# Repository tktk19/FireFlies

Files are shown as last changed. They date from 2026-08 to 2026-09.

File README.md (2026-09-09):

# FireFlies（電子ホタル集団同期明滅プロジェクト）

自然界のホタル（ゲンジボタル）に見られる**「集団同期明滅（引き込み現象）」**を超小型マイコン（ATtiny402）と光学センサのみで自律的に再現する電子ホタルプロジェクトです。

無線通信や親機（中央制御）を使わず、**「相手の放った光を見る $\to$ わずかに遅れて自分も光る」** という局所的な光フィードバックのみで、複数のホタルモジュールを並べると徐々に呼吸を合わせるように一斉同調発光します。

---

## 🌟 主な特徴・コンセプト

1. **自律分散型の協調発光（引き込みモデル）**
   - 個々のホタルが独立したタイマーで明滅します。
   - 消灯休止中に他のホタルの光を浴びると、休止時間を切り上げて 0.3〜1.2 秒のランダム遅延後に自分も発光を開始します。
   - 複数個が互いの光を浴び合うことで、蔵本モデル（非線形結合振動子の同期現象）のように群れ全体のリズムが自然と揃っていきます。

2. **リアルなゲンジボタルの明滅カーブ**
   - 単純な線形PWMではなく、二乗則を用いた呼吸のような立ち上がり（フェードイン）$\to$ 2〜4秒間の発光維持 $\to$ 余韻を残したフェードアウト $\to$ 4〜10秒間のゆらぎ休止を再現しています。

3. **超低消費電力スリープ（約 1 ヶ月の電池寿命）**
   - ATtiny402 内部の超低消費電力 32.768kHz 発振器と PIT（Periodic Interrupt Timer）を使用。
   - 待機・休止中は CPU を **Power Down スリープ（約 1μA）** させ、125ms（8Hz）ごとに一瞬だけ起きて受光センサをチェック。
   - 小型充電池（LIR2032: 実効約45mAh）でありながら、平均消費電流を約 50μA に抑え、**一晩で電池切れすることなく約 37 日間の連続稼働** を実現しています。

4. **安全なバッテリー過放電保護（UVLO）**
   - マイコン内部の基準電圧を用いて電源電圧（VDD）をリアルタイム監視。
   - 電圧が **3.0V を下回ると LED を短く2回点滅してお知らせし、永久ディープスリープ（消費電流 ~0.1μA）で安全に自動シャットダウン**。
   - 保護回路のないコイン型リチウムイオン電池が危険な過放電（1.2V等のセル破壊域）に陥るのを防ぎます。

5. **5V / 3.7V デュアル電源対応**
   - 設定マクロ（`#define USE_BATTERY_3V7`）を 1 行切り替えるだけで、USB/5V動作確認モードと 3.7V充電池モードに最適化された閾値・輝度が自動適用されます。

---

## 🛠 ハードウェア仕様

| 項目 | 仕様・部品 | 備考 |
| :--- | :--- | :--- |
| **マイコン (MCU)** | Microchip ATtiny402 (SOIC-8) | 超小型8ピンAVR (20MHz/内部発振) |
| **受光センサ** | フォトトランジスタ PT19-21C/L41/TR8 | PA7 / ADC (物理3ピン) + 100kΩ プルアップ |
| **発光素子** | チップLED (緑色 / 0603 or 1608) | PA2 / PWM (物理5ピン) + 4.7kΩ 電流制限抵抗 |
| **電源** | LIR2032 (3.7V 充電式コイン電池, 70mAh)<br>または 5V (USB電源) | CR2032電池ホルダー等に実装 |
| **書き込みインターフェース** | UPDI (MPLAB SNAP 等) | PA0 / UPDI (物理6ピン) + 4.7kΩ プルアップ |
| **筐体** | 3Dプリント外装（リアルなホタル形状） | 作成中 |

---

## 📄 設計資料・回路図リンク (`docs/`)

回路・基板に関する各種設計資料は [`docs/`](docs/) ディレクトリに収録されています。

* **回路図 (SVG)**: [`docs/circuit_v1.svg`](docs/circuit_v1.svg)
  * SchemDraw で描画された視認性の高い回路図
* **回路作図スクリプト**: [`docs/make_circuit_draw.py`](docs/make_circuit_draw.py)
  * Python の SchemDraw ライブラリを用いて回路図 SVG を自動生成するスクリプト
* **回路図 (PDF/EasyEDA)**: [`docs/SCH_Schematic1_2026-09-01.pdf`](docs/SCH_Schematic1_2026-09-01.pdf)
  * EasyEDA で設計された正式な回路図面
* **基板アートワーク (PDF/EasyEDA)**: [`docs/PCB_PCB1_2026-09-01.pdf`](docs/PCB_PCB1_2026-09-01.pdf)
  * 実装基板のレイアウトおよび配線パターン図

### 実機・動作確認ギャラリー (`docs/imgs/`)

| モジュール外観（斜視） | モジュール外観（上面） | 同期明滅テスト風景 |
| :---: | :---: | :---: |
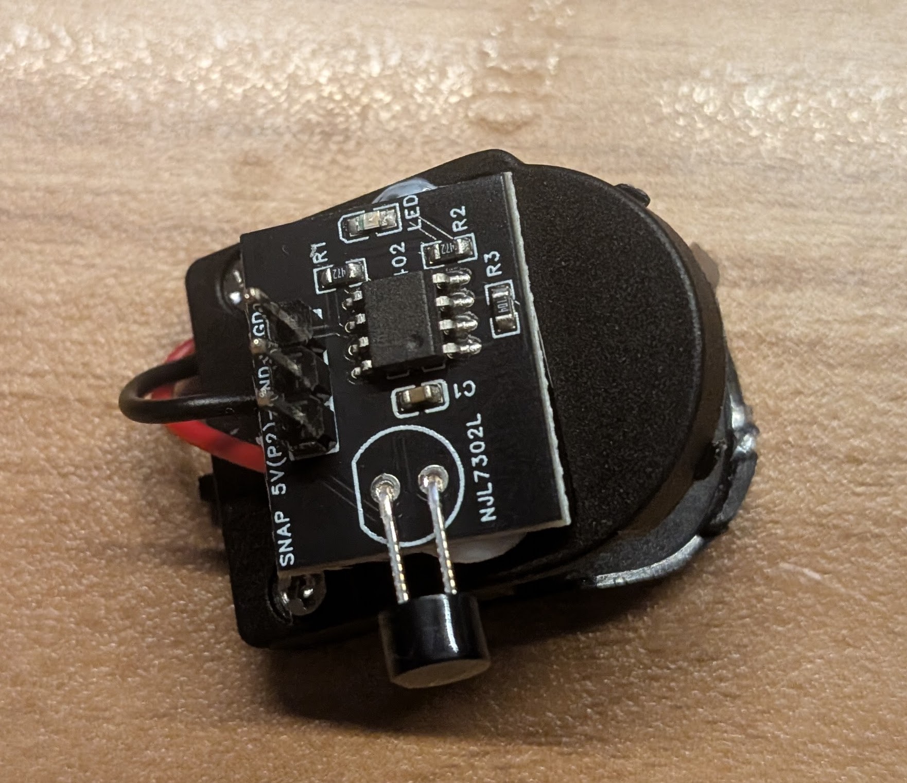
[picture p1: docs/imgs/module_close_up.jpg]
モジュール外観（斜視）
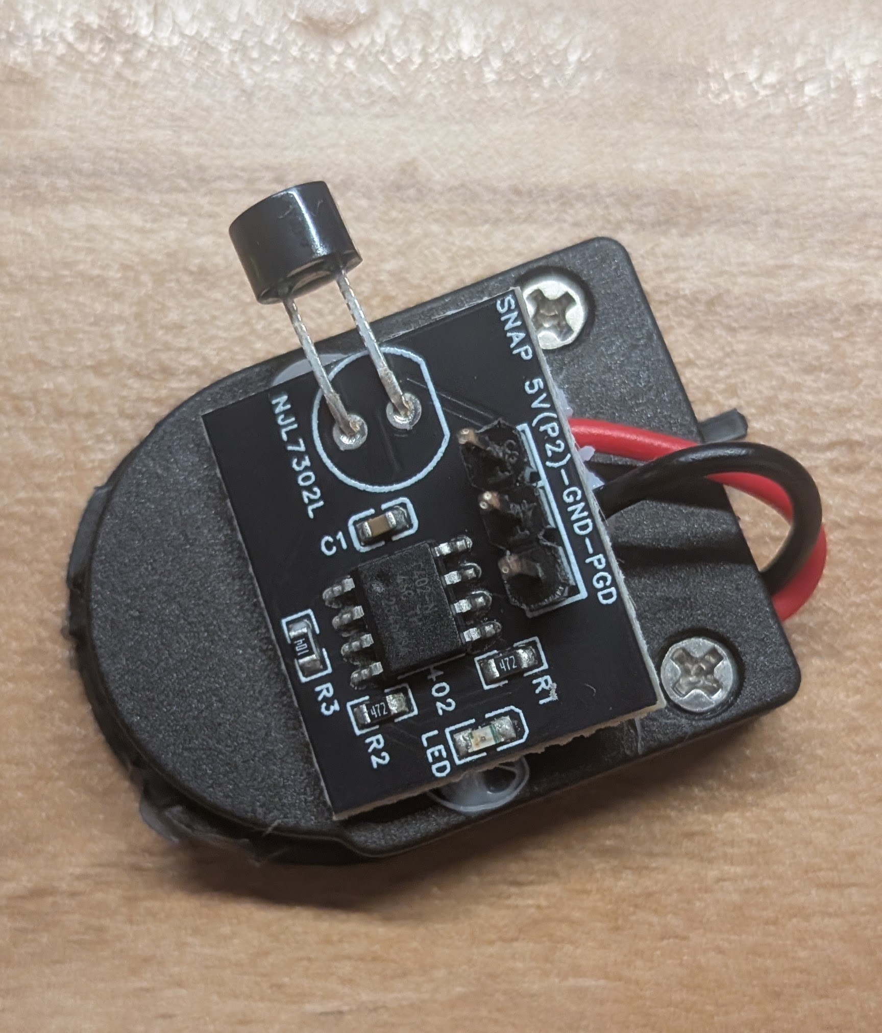
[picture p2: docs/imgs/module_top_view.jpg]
モジュール外観（上面）
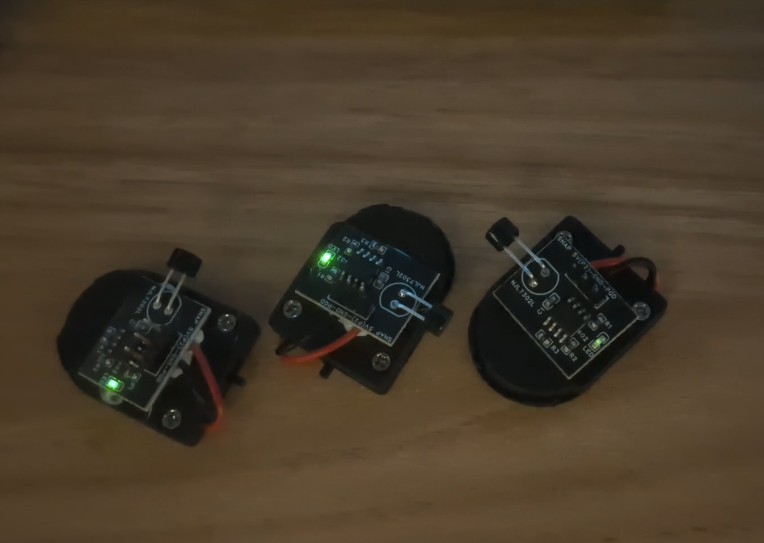
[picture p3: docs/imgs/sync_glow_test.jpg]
同期明滅テスト風景
|  |  |  |

---

## 💻 ソフトウェア・アルゴリズム (`Arduino/FireFly/`)

メインプログラム: [`Arduino/FireFly/FireFly.ino`](Arduino/FireFly/FireFly.ino)

### 状態遷移フロー

```mermaid
stateDiagram-v2
    [*] --> 昼間待機: 電源ON
    昼間待機 --> 夜間モード: 部屋を消灯 (ADC >= DARK_THRESHOLD)
    夜間モード --> 昼間待機: 部屋が明るい (ADC < DARK_THRESHOLD)

    state 夜間モード {
        [*] --> 発光処理: flashFirefly()
        発光処理 --> 自己受光ガード: スリープ2秒 (誤検出防止)
        自己受光ガード --> 休止待機: 4〜10秒 (125ms間隔スリープ)
        
        休止待機 --> 協調発光: 他の光検知 (ADC < LIGHT_THRESHOLD)
        協調発光 --> 発光処理: 0.3〜1.2秒ランダム遅延後
        
        休止待機 --> 自律発光: タイムアウト
        自律発光 --> 発光処理
    }

    夜間モード --> 電池切れシャットダウン: 電圧 < 3.0V (過放電保護)
    電池切れシャットダウン --> [*]: 永久ディープスリープ (0.1μA)
```

### 設定パラメータの比較

| パラメータ名 | 3.7V 充電池モード (`USE_BATTERY_3V7 = true`) | 5V 電源モード (`USE_BATTERY_3V7 = false`) | 説明 |
| :--- | :--- | :--- | :--- |
| `DARK_THRESHOLD` | **800** (約2.9V以上) | **819** (4.0V以上) | 周囲が暗くなった（夜）と判定するADC閾値 |
| `LIGHT_THRESHOLD` | **640** (約2.3V以下) | **720** (約3.5V以下) | 他のホタルの光を検知するADC閾値 |
| `ABSOLUTE_MAX_BRIGHTNESS` | **255** (100% PWM) | **200** (約78% PWM) | LED発光の最大輝度 |
| `LOW_BATTERY_VOLTAGE_MV` | **3000 mV** (3.0V) | **0 mV** (無効) | 過放電保護シャットダウン閾値 |

---

## 📂 ディレクトリ構成

```text
FireFlies/
├── README.md               # 本ドキュメント
├── Arduino/
│   ├── FireFly/
│   │   └── FireFly.ino     # ホタル同期発光ファームウェア（スリープ＆過放電保護内蔵）
│   └── LEDTest/            # LED・受光テスト用スケッチ
├── docs/                   # 回路図・基板設計資料
│   ├── circuit_v1.svg      # 回路図 (SVG)
│   ├── make_circuit_draw.py# 回路作図スクリプト
│   ├── SCH_Schematic1_2026-09-01.pdf # 回路図面 (PDF)
│   └── PCB_PCB1_2026-09-01.pdf       # 基板レイアウト図面 (PDF)
├── 3DModel/                # 外装・モデルデータ (.3mf, .png, Pythonスクリプト)
└── EasyEDA/                # EasyEDA プロジェクトファイル格納用
```

---

## 🔧 ビルド・書き込み方法

1. **開発環境の準備**:
   * Arduino IDE をインストール。
   * ボードマネージャに **`megaTinyCore`**（by Spence Konde）を導入。
2. **ボード設定**:
   * ボード: `ATtiny402/202`
   * チップ: `ATtiny402`
   * クロック: `20MHz Internal`（または `16MHz`）
3. **書き込み**:
   * プログラマに UPDI 対応機器（MPLAB SNAP、jtag2updi、SerialUPDI 等）を選択し、ファームウェアを書き込みます。

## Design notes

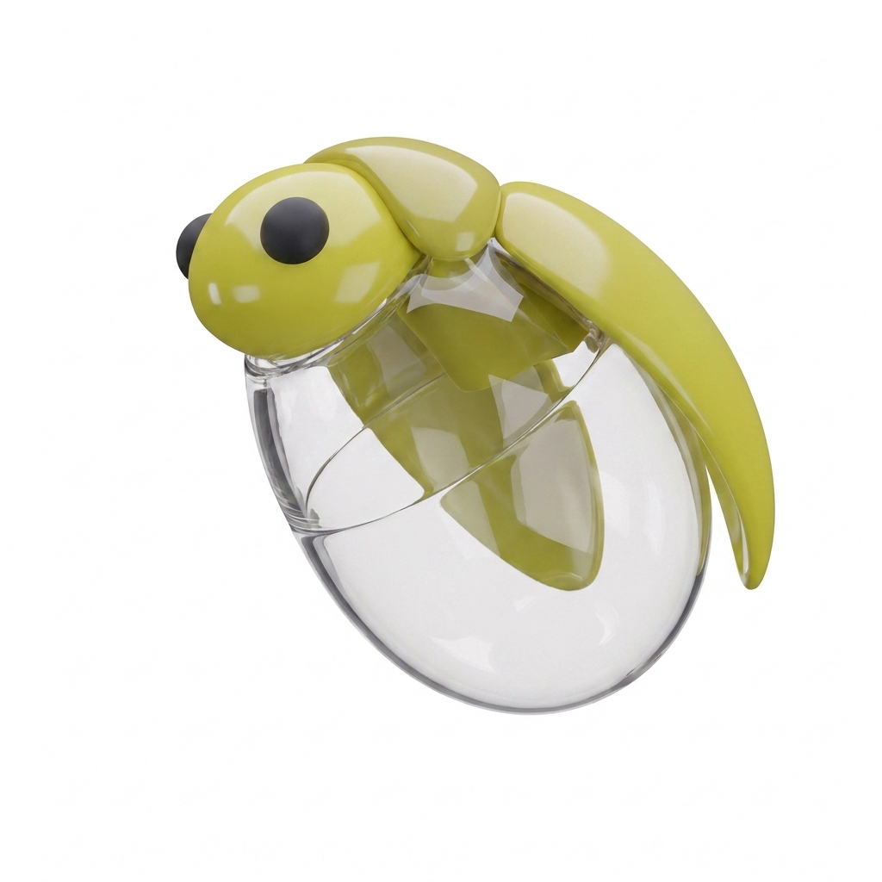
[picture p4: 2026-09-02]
3DModel/Prototype11.png

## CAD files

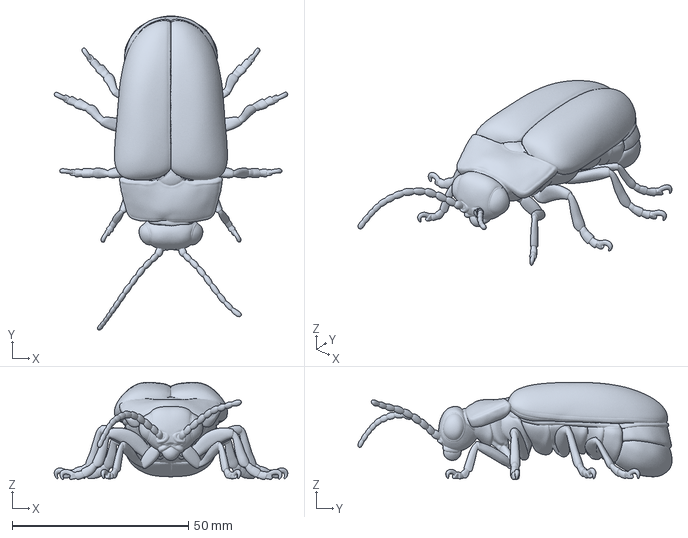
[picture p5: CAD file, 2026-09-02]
3DModel/Prototype01_Overall.3mf
66.3 x 89.1 x 27.6 mm

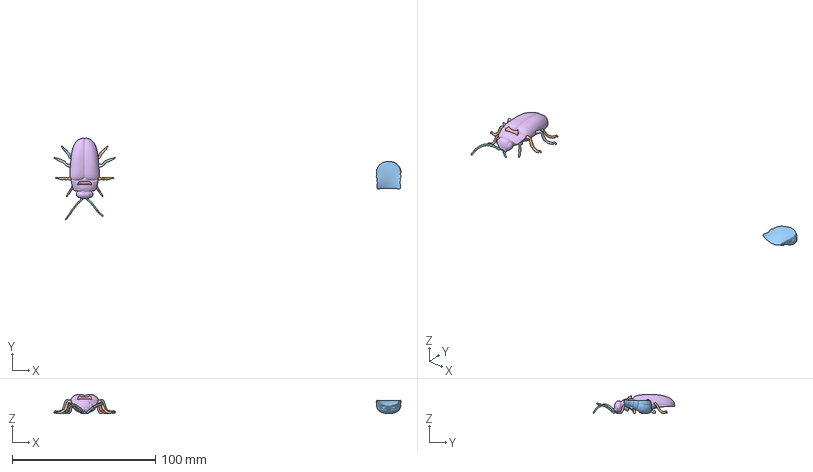
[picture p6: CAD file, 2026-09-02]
3DModel/Prototype02_part-segmentation.3mf
242.4 x 57.0 x 13.3 mm

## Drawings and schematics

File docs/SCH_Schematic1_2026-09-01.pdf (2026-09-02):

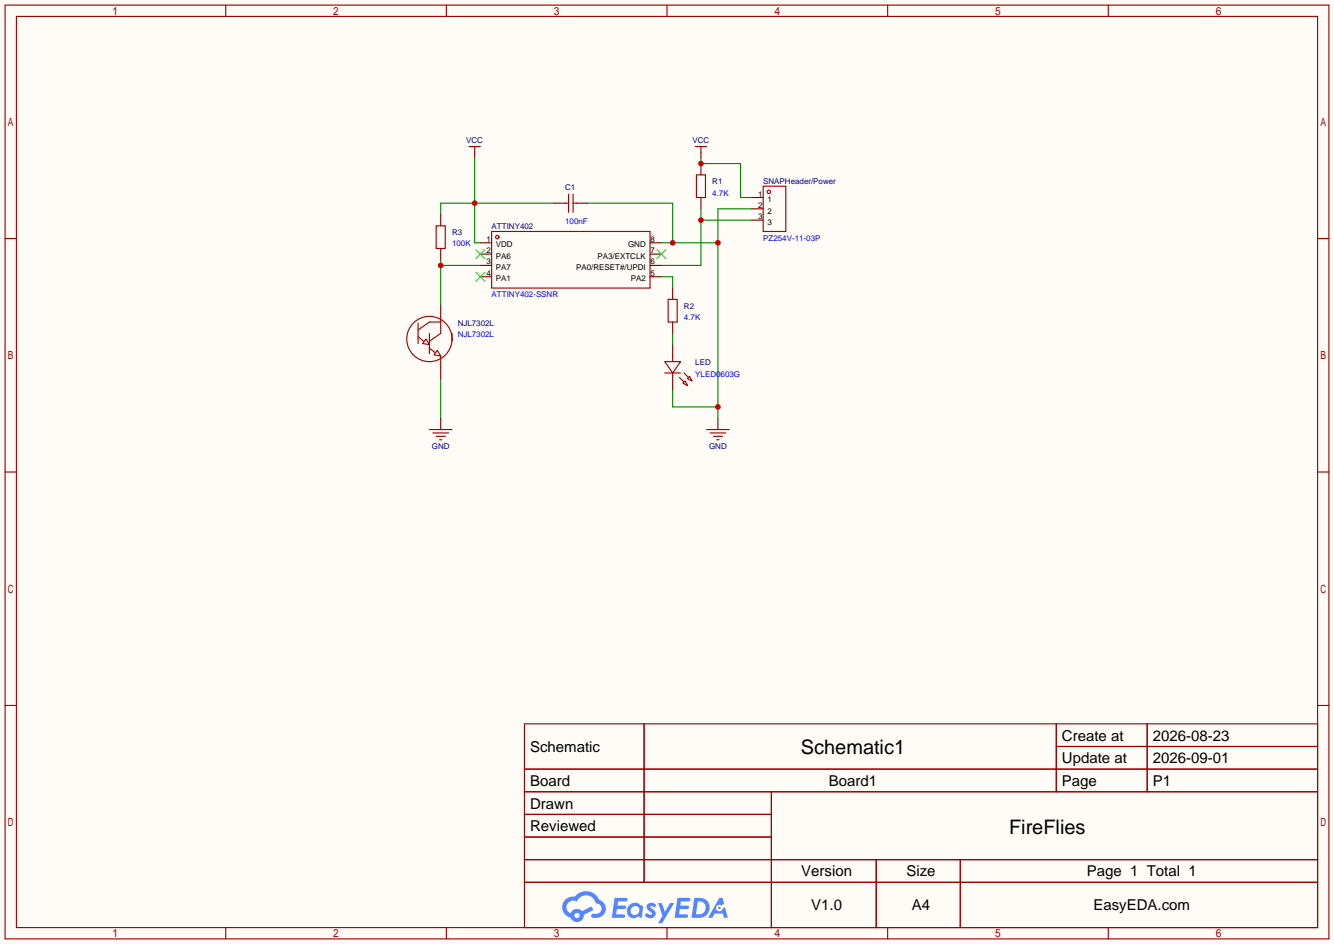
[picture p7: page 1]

Schematic | Schematic1 | Create at | 2026-08-23

Update at | 2026-09-01

Board | Board1 | Page | P1
Drawn | | FireFlies
Reviewed

Version | Size | Page 1 Total 1
V1.0 | A4 | EasyEDA.com

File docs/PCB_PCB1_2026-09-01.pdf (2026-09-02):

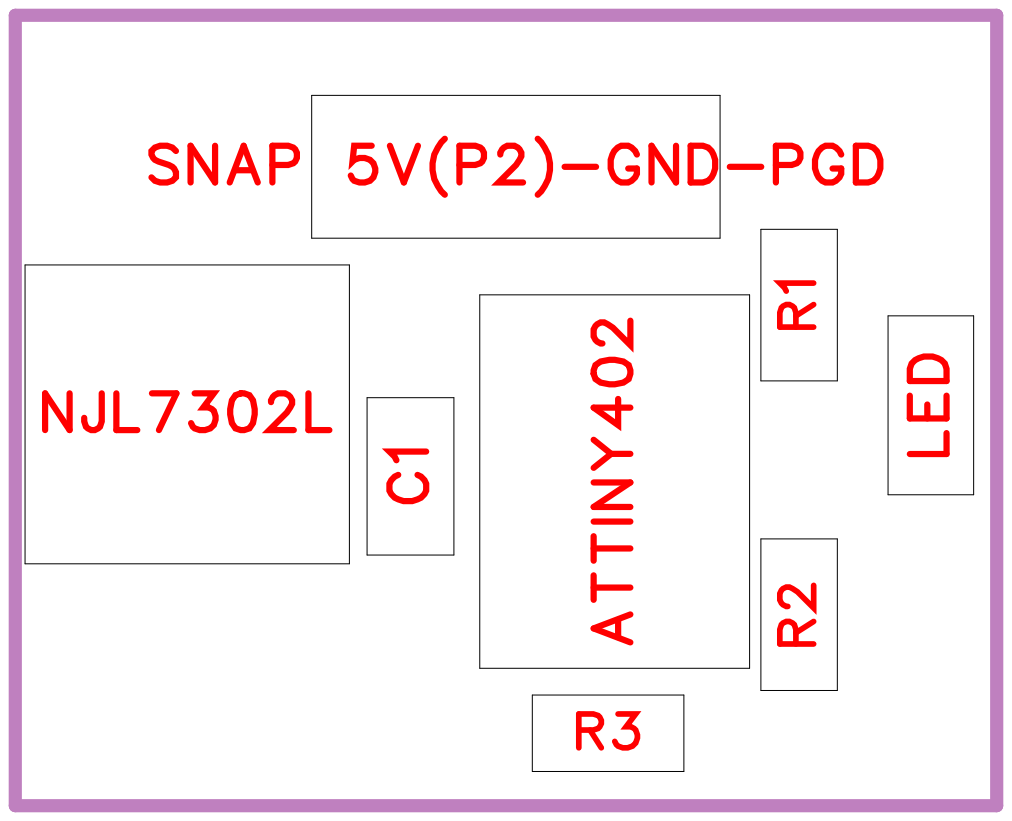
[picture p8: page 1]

No. | Quantity | Comment | Designator | Footprint | Value | Manufacturer Part | Manufacturer | Supplier Part | Supplier
1 | 1 | ATTINY402-SSNR | ATTINY402 | SOIC-8_L4.9 -W3.9-P1.27-LS6.0-BL | | ATTINY402-SSNR | MICROCHIP( 美国微芯) | C616056 | LCSC
2 | 1 | 100nF | C1 | C0603 | 100nF | CT41G-0603 -2X1-50V-0.1 uF-K(N) | TORCH(火炬 ) | C125205 | LCSC
3 | 1 | YLED0603G | LED | LED0603-FD | | YLED0603G | YONGYUTAI (永裕泰) | C19273151 | LCSC
4 | 1 | NJL7302L | NJL7302L | SENSOR-TH _JRC_NJL73 02L-F3 | | NJL7302L | JRC | C3039934 | LCSC
5 | 2 | 4.7K | R1,R2 | R0603 | 4.7K
6 | 1 | 100K | R3 | R0603 | 100K
7 | 1 | PZ254V-11-0 3P | SNAP 5V(P2)-GND-PGD | HDR-TH_3P-P2.54-V-M_P Z254V-11-03 P | | PZ254V-11-0 3P | XFCN(兴飞) | C2937625 | LCSC

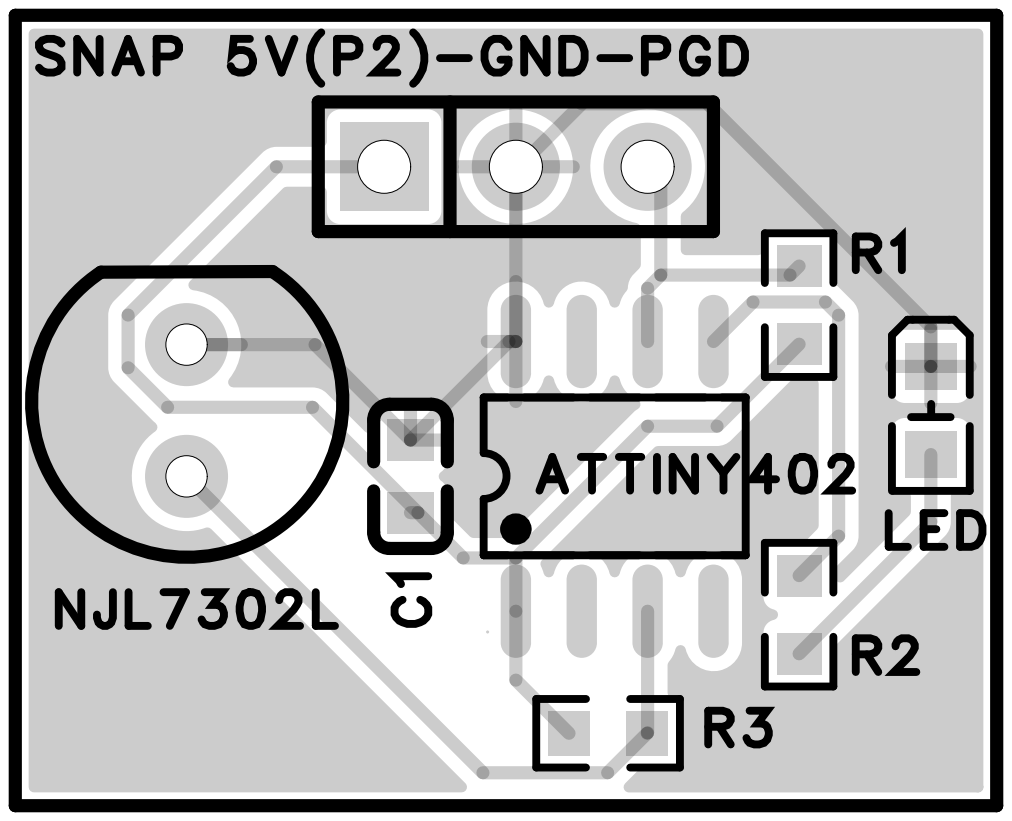
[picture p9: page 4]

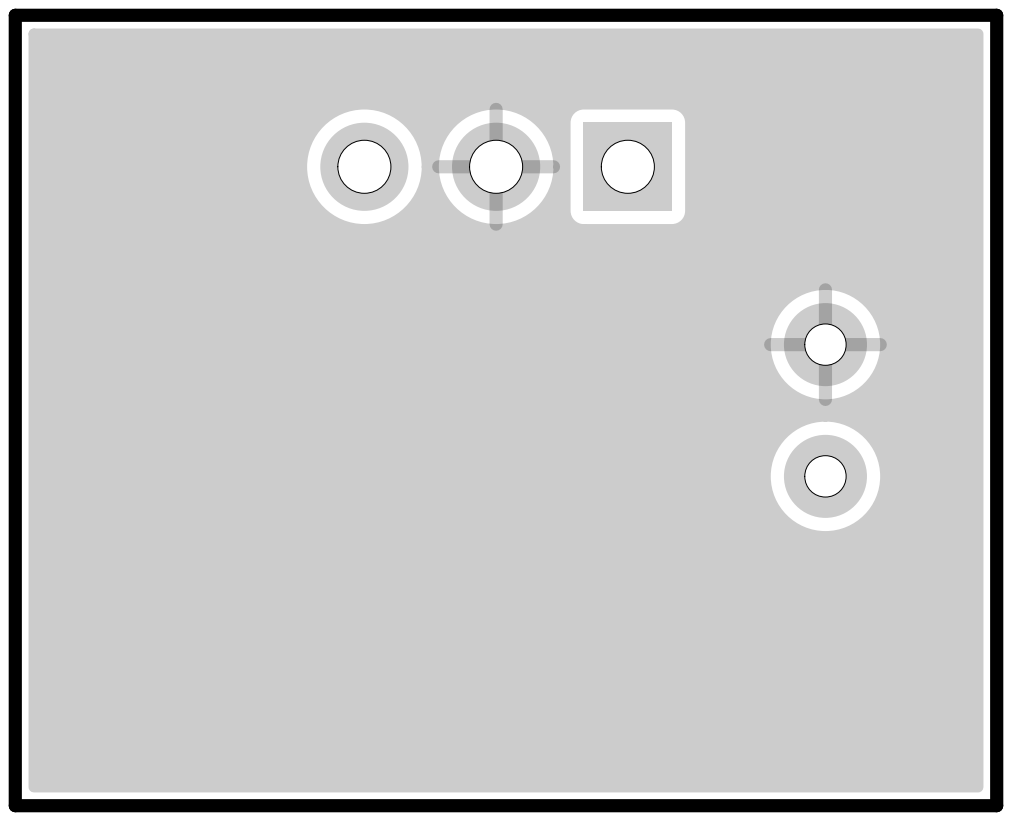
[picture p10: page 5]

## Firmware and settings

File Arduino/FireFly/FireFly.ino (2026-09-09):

// ATtiny402 ゲンジボタル（省電力スリープ＆過放電保護版）
// 物理3ピン (PA7) : A7 として指定
// 物理5ピン (PA2) : PWM LED

#include <avr/sleep.h>
#include <avr/interrupt.h>
#include <megaTinyCore.h>

// ==========================================
// 電源設定の切り替え
// ==========================================
// 3.7V 充電池 (LIR2032 等) を使用する場合は true、
// 5V (USB / モバイルバッテリー等) を使用する場合は false に設定してください。
#define USE_BATTERY_3V7 true

const int sensorPin = A7;     // PA7 は アナログチャンネル A7 (物理3ピン)
const int ledPin = PIN_PA2;   // 物理5ピン (PA2)

#if USE_BATTERY_3V7
  // ----------------------------------------------------
  // 3.7V 充電池（LIR2032: 3.4V〜4.2V）駆動時
  // ----------------------------------------------------
  // 暗所判定: 約 2.9V 以上 (ADC 800) で「夜」と判定
  const int DARK_THRESHOLD = 800;

  // 光検知判定: 5V時の720(ΔV≒1.48V相当)を3.7V基準に換算すると約614〜650。
  // 相手のホタルも3.7V駆動でLEDが暗めになることを考慮し、やや高感度な640に設定。
  const int LIGHT_THRESHOLD = 640;

  // 3.7V時は電流制限抵抗(4.7kΩ)によりLED電流が減るため、最大輝度を255(フル)にして光量を確保
  const int ABSOLUTE_MAX_BRIGHTNESS = 255;

  // 過放電保護: 3.0V (3000mV) を切ったら強制シャットダウンして電池を保護
  const int LOW_BATTERY_VOLTAGE_MV = 3000;

#else
  // ----------------------------------------------------
  // 5V（USB / 5Vバッテリー）駆動時
  // ----------------------------------------------------
  // 暗所判定: 4.0V 以上 (ADC 819) で「夜」と判定
  const int DARK_THRESHOLD = 819;

  // 光検知判定: ユーザー検証済みの 720 (約3.52V以下で検知)
  const int LIGHT_THRESHOLD = 720;

  // 5V時の最大輝度
  const int ABSOLUTE_MAX_BRIGHTNESS = 200;

  // 5V電源時は過放電保護無効
  const int LOW_BATTERY_VOLTAGE_MV = 0;
#endif

// ==========================================
// 省電力タイマー（PIT: Periodic Interrupt Timer）設定
// ==========================================
// 125ms ごとにスリープから復帰するための割り込み
ISR(RTC_PIT_vect) {
  RTC.PITINTFLAGS = RTC_PI_bm; // 割り込みフラグクリア
}

void initPIT() {
  while (RTC.PITSTATUS & RTC_CTRLBUSY_bm); // ビジー解除待ち
  RTC.CLKSEL = RTC_CLKSEL_INT32K_gc;     // 内部超低消費電力 32.768kHz 発振器
  RTC.PITINTCTRL = RTC_PI_bm;             // PIT割り込み有効化
  RTC.PITCTRLA = RTC_PERIOD_CYC4096_gc | RTC_PITEN_bm; // 4096周期 = 125ms (8Hz)
}

// 約125msのPower Downディープスリープ（CPU停止・消費電流約1μA）
void sleep125ms() {
  set_sleep_mode(SLEEP_MODE_PWR_DOWN);
  sleep_enable();
  sleep_cpu();
  sleep_disable();
}

// 指定ミリ秒を 125ms 単位のスリープで待機
void sleepMsDuration(unsigned long ms) {
  unsigned int steps = ms / 125;
  for (unsigned int i = 0; i < steps; i++) {
    sleep125ms();
  }
}

// ==========================================
// 過放電保護チェック（3.0V未満で完全停止）
// ==========================================
void checkBatteryProtection() {
#if USE_BATTERY_3V7
  uint16_t vdd = readSupplyVoltage(); // 電源電圧(mV)を取得
  if (vdd > 0 && vdd < LOW_BATTERY_VOLTAGE_MV) {
    // 電池切れサイン: LEDを短く2回点滅
    for (int i = 0; i < 2; i++) {
      analogWrite(ledPin, 30);
      delay(30);
      analogWrite(ledPin, 0);
      delay(100);
    }

    // 全ペリフェラル停止
    RTC.PITCTRLA = 0;             // PITタイマー停止
    RTC.PITINTCTRL = 0;
    ADC0.CTRLA &= ~ADC_ENABLE_bm; // ADC停止
    digitalWrite(ledPin, LOW);

    // 永久ディープスリープ（電池交換・再充電まで完全停止、消費電流 ~0.1μA）
    set_sleep_mode(SLEEP_MODE_PWR_DOWN);
    sleep_enable();
    cli(); // 全割り込み禁止
    while (1) {
      sleep_cpu();
    }
  }
#endif
}

void setup() {
  // ADCの基準電圧を電源電圧（VDD）に明示的に設定
#if defined(VDD)
  analogReference(VDD);
#endif

  pinMode(ledPin, OUTPUT);
  randomSeed(analogRead(PIN_PA1));

  initPIT(); // 超低消費電力PITタイマー開始
}

void flashFirefly() {
  int maxLimit = random(10, ABSOLUTE_MAX_BRIGHTNESS + 1);
  int upDelay = random(5, 7);
  int downDelay = random(8, 12);

  for (int i = 0; i <= 255; i++) {
    long iSquared = (long)i * i;
    int pwmVal = (int)((iSquared * maxLimit) / 65025);
    analogWrite(ledPin, pwmVal);
    delay(upDelay); 
  }

  delay(random(2000, 4000));

  for (int i = 255; i >= 0; i--) {
    long iSquared = (long)i * i;
    int pwmVal = (int)((iSquared * maxLimit) / 65025);
    analogWrite(ledPin, pwmVal);
    delay(downDelay); 
  }

  analogWrite(ledPin, 0);
}

void loop() {
  // バッテリー電圧チェック（3.0V未満なら過放電防止で自動シャットダウン）
  checkBatteryProtection();

  int currentVal = analogRead(sensorPin);

  // 暗所判定（DARK_THRESHOLD以上の場合のみ「夜」と判定）
  if (currentVal >= DARK_THRESHOLD) {

    flashFirefly();

    // 自己受光ガード（自発光直後の誤反応を防止: 2000ms間スリープ）
    sleepMsDuration(2000);

    // 休止期間（4〜10秒間）
    // 125ms間隔でスリープしながら受光センサをチェック（平均待機電流を数十μAに抑制）
    int totalSteps = random(32, 81); // 32*125ms=4000ms 〜 80*125ms=10000ms

    for (int step = 0; step < totalSteps; step++) {
      sleep125ms(); // 125ms間はCPU完全停止（消費電流 約1μA）

      int sensorVal = analogRead(sensorPin);

      // 他のホタルの光を検知（sensorVal < LIGHT_THRESHOLD）したら協調発光
      if (sensorVal < LIGHT_THRESHOLD) {
        delay(random(300, 1201)); // 同期発光までのわずかな応答揺らぎ
        break; 
      }
    }

  } else {
    // 昼間・明かりありの場合は1秒間スリープして待機
    digitalWrite(ledPin, LOW);
    sleepMsDuration(1000); 
  }
}

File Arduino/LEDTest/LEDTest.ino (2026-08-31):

// ATtiny402 東日本型ゲンジボタル明滅（超スロー明滅＆5〜30秒ランダム休止）
// 物理ピン: 5ピン (PA2)

const int ledPin = PIN_PA2; // 物理5ピン (PA2)

// 明るさの上限設定（元の255に対して30：控えめな発光）
const int MAX_BRIGHTNESS = 30; 

void setup() {
  pinMode(ledPin, OUTPUT);
  
  // 未接続ピンのアナログノイズで乱数を初期化
  randomSeed(analogRead(PIN_PA1));
}

void loop() {
  // 1. じわ〜〜っと明るく（約 6.0 秒：30ステップ × 180ms）
  for (int i = 0; i <= MAX_BRIGHTNESS; i++) {
    long longI = i;
    int brightness = (int)((longI * longI) / MAX_BRIGHTNESS);
    
    analogWrite(ledPin, brightness);
    delay(180); 
  }

  // ピーク時の余韻（約 0.5 秒）
  delay(500);

  // 2. じわ〜〜っと消灯（約 7.5 秒：30ステップ × 225ms）
  for (int i = MAX_BRIGHTNESS; i >= 0; i--) {
    long longI = i;
    int brightness = (int)((longI * longI) / MAX_BRIGHTNESS);
    
    analogWrite(ledPin, brightness);
    delay(225); 
  }

  // 完全消灯（0出力）
  analogWrite(ledPin, 0);

  // 3. 完全消灯（静寂）：5秒 〜 30秒 の間でランダムに待機
  long sleepTime = random(5000, 30001);
  delay(sleepTime);
}

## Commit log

2026-08-31 Update - LED点滅テストプログラムを追加
2026-08-31 Update - 回路図修正＆Update
2026-08-31 Update - プログラムをUpdate - 回路図をUpdate
2026-09-02 Update - 回路図・PCB設計図を更新
2026-09-02 Update - 3DModel追加
    [Prototype01_Overall.3mf, Prototype02_part-segmentation.3mf]
2026-09-08 Update - 作成した基板での動作確認版
2026-09-09 Update - 最大輝度を嫁指摘で修正
2026-09-09 Update - バッテリ電圧の違い/閾値の違いをフラグ実装 - 協調発光ロジックをより鋭い閾値に
2026-09-09 feat: README.mdを生成、バッテリ消費を抑えるためスリープを有効に
